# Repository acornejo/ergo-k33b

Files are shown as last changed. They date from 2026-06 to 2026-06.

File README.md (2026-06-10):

# ergo-k33b

A 56-key split/unified ortholinear keyboard with an integrated trackpad, designed in [Ergogen](https://ergogen.xyz/) and routed manually in KiCad.

## Overview

The ergo-k33b is a custom keyboard PCB featuring a symmetric 6×4 column-staggered matrix on each half, palm modifier keys, a 3-key thumb cluster per side, and an optional 65mm×50mm Azoteq TPS65 trackpad mounted in the center of the board.

The board uses a single unified PCB that mirrors the left and right halves — no split cable required.

## Images

### PCB — Top
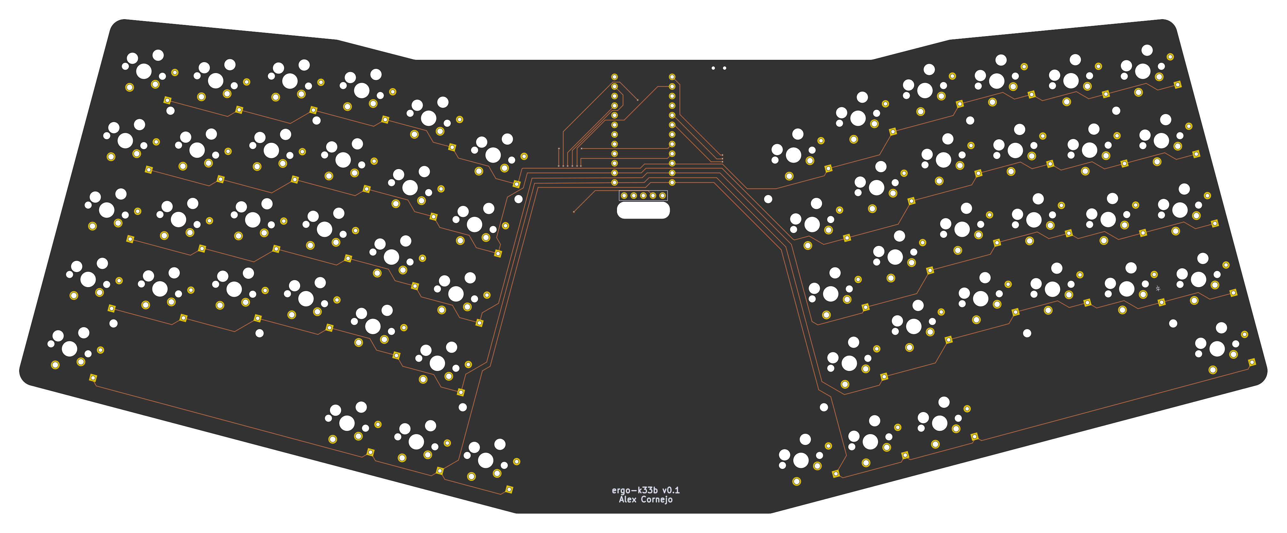
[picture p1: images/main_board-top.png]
PCB Top


### PCB — Bottom
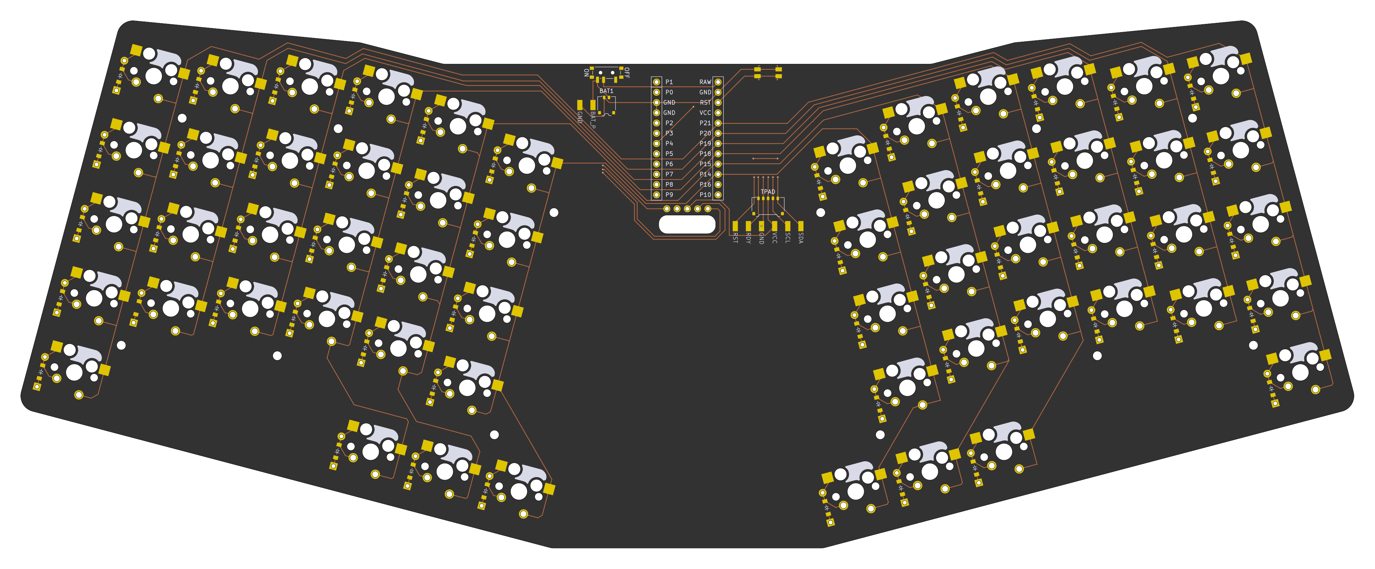
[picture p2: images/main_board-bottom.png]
PCB Bottom


### Front Plate
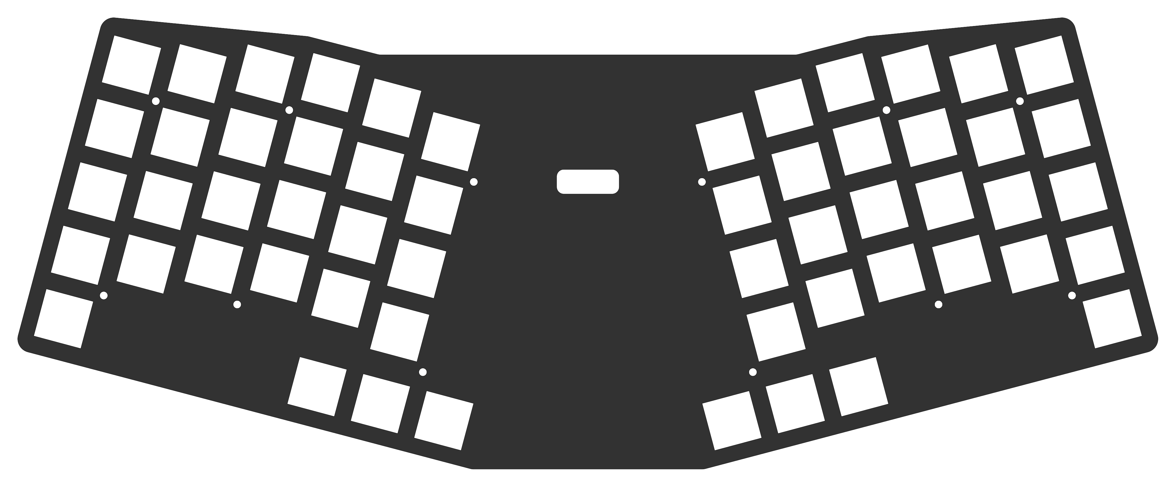
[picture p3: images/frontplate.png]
Front Plate


### Back Plate
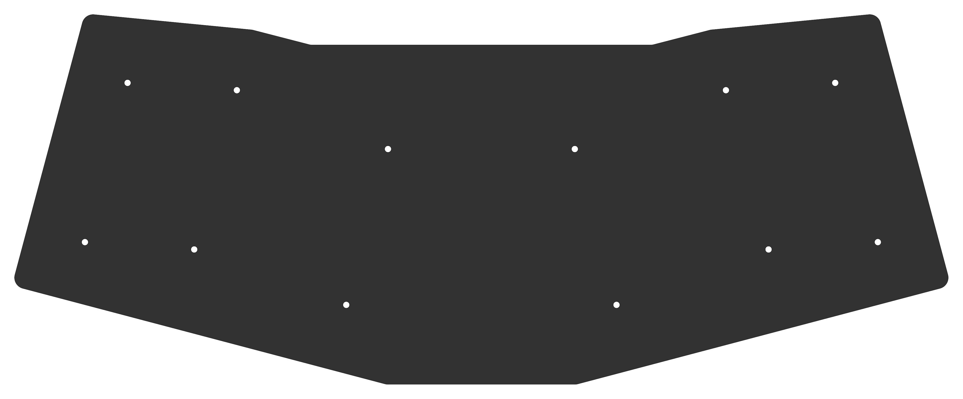
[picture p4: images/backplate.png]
Back Plate


### Case
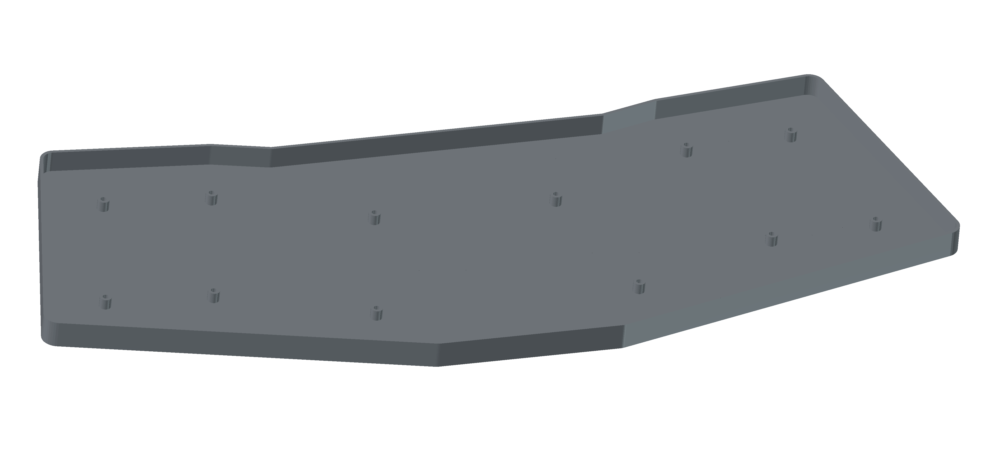
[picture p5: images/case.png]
Case


## Key Layout

- **Total keys:** 56 (10 palm keys + 6 thumb keys + 40 matrix keys)
- **Matrix:** 6 columns × 4 rows per side, with column stagger:
  - Outer/pinky columns: +0/+2.5 mm stagger
  - Ring column: +5 mm stagger
  - Middle column: +2.5 mm stagger
  - Index column: −2.5 mm stagger
  - Inner column: −5 mm stagger
- **Thumb cluster:** 3 keys per side, splayed outward from the inner-bottom matrix position
- **Palm keys:** 1 key per side below the outer column, intended for modifier keys
- **Switch type:** Cherry MX (5-pin), with optional hotswap socket support

## Hardware

| Component | Part | Notes |
|---|---|---|
| MCU | [Nice!Nano](https://nicekeyboards.com/nice-nano/) (nRF52840 SuperMini) | Mounted on the back, centered between halves |
| Display | [Nice!View](https://nicekeyboards.com/nice-view/) | Optional; SPI via P1/P2/P3 |
| Trackpad | [Azoteq TPS65](https://www.azoteq.com/) (65mm × 50mm) | Optional; I²C via P4/P5, ready signal P0 |
| Switches | Cherry MX 5-pin | Hotswap and solder options |
| Diodes | SOD-123 (SMD) + THT | Both footprints populated; one per key |
| Battery connector | Molex Pico EZmate 1×2 | Also exposes BAT\_P / GND solder pads as an alternative |
| Trackpad connector | Molex Pico EZmate 1×5 | Also exposes RST / RDY / GND / VCC / SCL / SDA solder pads as an alternative |
| Power switch | SMD side-mount | On the back of the board |
| Reset button | SMD side-mount | On the back of the board |

### Connector choice

Both the battery and trackpad use [Molex Pico EZmate](https://www.molex.com/en-us/products/connectors/wire-to-board-connectors/pico-ezmate-connectors) connectors rather than the more common JST-PH standard. Pico EZmate has a lower profile (1.48 mm mated height vs. 3.0 mm for JST-PH), which keeps the overall board assembly thinner. Each connector also has corresponding solder pad footprints on the PCB, so you can wire the battery or trackpad directly without a connector if preferred.

## PCB Design

The PCB was designed using [Ergogen](https://ergogen.xyz/) v4.2 to generate the board outline, key positions, and component footprints from `ergogen/config.yaml`. Routing was done manually in KiCad. The freerouting scripts in this repo are provided for experimentation only.

Three PCBs are generated from the Ergogen config:

| PCB | Description |
|---|---|
| `main_board` | The keyboard PCB with all switches, diodes, MCU, and connectors |
| `frontplate` | Switch plate with key cutouts and screw holes |
| `backplate` | Bottom cover plate with screw holes |

A `bottom_case` 3D model (STL) is also generated from the Ergogen outlines using OpenJSCAD.

### Pinout (nRF52840 SuperMini)

| Pin | Function |
|---|---|
| P21 | Column: outer |
| P20 | Column: pinky |
| P19 | Column: ring |
| P18 | Column: middle |
| P15 | Column: index |
| P14 | Column: inner |
| P10 | Row: bottom |
| P8 | Row: home |
| P16 | Row: top |
| P7 | Row: num |
| P9 | Row: thumb cluster |
| P13 | Row: palm keys |
| P0 | Trackpad RDY |
| P4 | Trackpad SCL (I²C) |
| P5 | Trackpad SDA (I²C) |
| P6 | Trackpad RST |
| P1 | Nice!View CS |
| P2 | Nice!View MOSI |
| P3 | Nice!View SCK |

## Repository Structure

```
ergogen/
  config.yaml       # Full Ergogen board definition
output/
  pcbs/             # Generated KiCad PCB files
  cases/            # Generated OpenJSCAD and STL files
  outlines/         # Generated outline DXFs
  gerbers/          # Fabrication outputs
scripts/
  boards.kibot.yaml # KiBot config for main board exports
  default.kibot.yaml# KiBot config for plate exports
  export_dsn.py     # Export KiCad PCB to Specctra DSN
  import_ses.py     # Import Specctra SES back to KiCad
  freerouting.rules # Freerouting design rules
main_board.kicad_pcb # Hand-routed main board (source of truth)
build.sh            # Docker-based build script (KiBot + Freerouting)
images/             # Board renders
```

## Building

### Prerequisites

- [Node.js](https://nodejs.org/) (for Ergogen and OpenJSCAD CLI)
- [Docker](https://www.docker.com/) (for KiBot and Freerouting via containers)

### Generate PCB and case files from Ergogen

```bash
npm install
npm run build
```

This runs Ergogen to regenerate all PCBs, outlines, and case STL files under `output/`.

### Export Gerbers and run autorouting

```bash
./build.sh
```

This uses Docker to:
1. Run [KiBot](https://github.com/INTI-CMNB/KiBot) to export Gerbers for plates and boards
2. Export the board to Specctra DSN format
3. Autoroute with [Freerouting](https://github.com/freerouting/freerouting) (25 passes)
4. Import the routed SES back to KiCad and re-export Gerbers

> **Note:** The hand-routed `main_board.kicad_pcb` at the repo root is the production board. The autorouted output is for experimentation only.

### Clean generated output

```bash
npm run clean
```

## Firmware

The Nice!Nano runs [ZMK Firmware](https://zmk.dev/). Create a ZMK config repo with a shield definition matching the matrix pinout above.

## License

See [LICENSE](LICENSE).

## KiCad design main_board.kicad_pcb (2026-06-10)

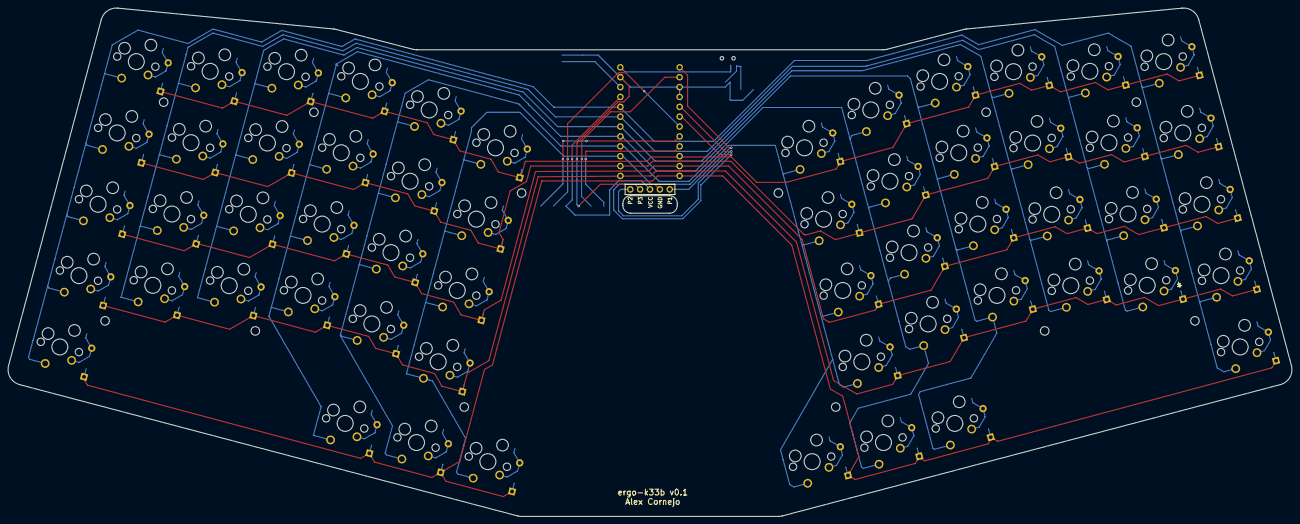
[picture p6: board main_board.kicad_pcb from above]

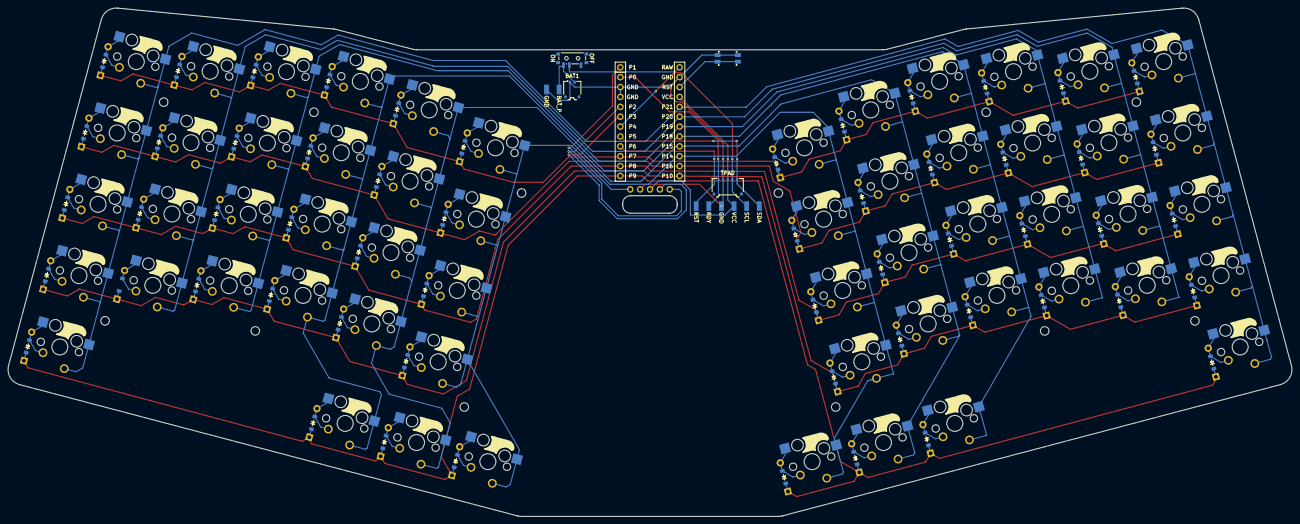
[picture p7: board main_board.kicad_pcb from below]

Board: 2 copper layers, 330.3 x 130.8 mm, 132 parts (116 on the bottom side), 79 nets.

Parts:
BAT1: Molex_Pico-EZmate_78171-0002_1x02-1MP_P1.20mm_Vertical
BAT_PADS1: pads
D1, D2, D3, D4, D5, D6, D7, D8, D9, D10, D11, D12, D13, D14, D15, D16, D17, D18, D19, D20, D21, D22, D23, D24, D25, D26, D27, D28, D29, D30, D31, D32, D33, D34, D35, D36, D37, D38, D39, D40, D41, D42, D43, D44, D45, D46, D47, D48, D49, D50, D51, D52, D53, D54, D55, D56: diode_tht_sod123
DISP1: display_nice_view
MCU1: mcu_supermini_nrf52840
MH1, MH2, MH3, MH4, MH5, MH6, MH7, MH8, MH9, MH10, MH11, MH12: mounting_hole_npth
PWR1: power_switch_smd_side
RST1: reset_switch_smd_side
S1, S2, S3, S4, S5, S6, S7, S8, S9, S10, S11, S12, S13, S14, S15, S16, S17, S18, S19, S20, S21, S22, S23, S24, S25, S26, S27, S28: switch_mx
S29, S30, S31, S32, S33, S34, S35, S36, S37, S38, S39, S40, S41, S42, S43, S44, S45, S46, S47, S48, S49, S50, S51, S52, S53, S54, S55, S56: switch_mx2
TPAD: Molex_Pico-EZmate_78171-0005_1x05-1MP_P1.20mm_Vertical
TPAD_PADS1: pads

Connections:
BAT_P: BAT1.2, BAT_PADS1.1, PWR1.3
GND: BAT1.1, BAT_PADS1.2, DISP1.4, MCU1.3, MCU1.4, MCU1.23, RST1.1, RST1.3, TPAD.2, TPAD_PADS1.4
P0: MCU1.2, TPAD.1, TPAD_PADS1.5
P1: DISP1.5, MCU1.1
P2: DISP1.1, MCU1.5
P3: DISP1.2, MCU1.6
P4: MCU1.7, TPAD.4, TPAD_PADS1.2
P5: MCU1.8, TPAD.5, TPAD_PADS1.1
P6: MCU1.9, TPAD_PADS1.6
P7: D4.1, D8.1, D12.1, D16.1, D20.1, D24.1, D32.1, D36.1, D40.1, D44.1, D48.1, D52.1, MCU1.10
P8: D2.1, D6.1, D10.1, D14.1, D18.1, D22.1, D30.1, D34.1, D38.1, D42.1, D46.1, D50.1, MCU1.11
P9: D25.1, D26.1, D27.1, D28.1, D53.1, D54.1, D55.1, D56.1, MCU1.12
P10: D1.1, D5.1, D9.1, D13.1, D17.1, D21.1, D29.1, D33.1, D37.1, D41.1, D45.1, D49.1, MCU1.13
P14: MCU1.20, S1.1, S2.1, S3.1, S4.1, S28.1, S29.1, S30.1, S31.1, S32.1, S56.1
P15: MCU1.19, S5.1, S6.1, S7.1, S8.1, S33.1, S34.1, S35.1, S36.1
P16: D3.1, D7.1, D11.1, D15.1, D19.1, D23.1, D31.1, D35.1, D39.1, D43.1, D47.1, D51.1, MCU1.14
P18: MCU1.18, S9.1, S10.1, S11.1, S12.1, S37.1, S38.1, S39.1, S40.1
P19: MCU1.17, S13.1, S14.1, S15.1, S16.1, S25.1, S41.1, S42.1, S43.1, S44.1, S53.1
P20: MCU1.16, S17.1, S18.1, S19.1, S20.1, S26.1, S45.1, S46.1, S47.1, S48.1, S54.1
P21: MCU1.15, S21.1, S22.1, S23.1, S24.1, S27.1, S49.1, S50.1, S51.1, S52.1, S55.1
RAW: MCU1.24, PWR1.2
RST: MCU1.22, RST1.2, RST1.4
VCC: DISP1.3, MCU1.21, TPAD.3, TPAD_PADS1.3
far_cluster: D27.2, S27.2
home_cluster: D26.2, S26.2
index_bottom: D17.2, S17.2
index_home: D18.2, S18.2
index_num: D20.2, S20.2
index_top: D19.2, S19.2
inner_bottom: D21.2, S21.2
inner_home: D22.2, S22.2
inner_num: D24.2, S24.2
inner_top: D23.2, S23.2
middle_bottom: D13.2, S13.2
middle_home: D14.2, S14.2
middle_num: D16.2, S16.2
middle_top: D15.2, S15.2
mirror_far_cluster: D55.2, S55.2
mirror_home_cluster: D54.2, S54.2
mirror_index_bottom: D45.2, S45.2
mirror_index_home: D46.2, S46.2
mirror_index_num: D48.2, S48.2
mirror_index_top: D47.2, S47.2
mirror_inner_bottom: D49.2, S49.2
mirror_inner_home: D50.2, S50.2
mirror_inner_num: D52.2, S52.2
mirror_inner_top: D51.2, S51.2
mirror_middle_bottom: D41.2, S41.2
mirror_middle_home: D42.2, S42.2
mirror_middle_num: D44.2, S44.2
mirror_middle_top: D43.2, S43.2
mirror_near_cluster: D53.2, S53.2
mirror_outer_bottom: D29.2, S29.2
mirror_outer_home: D30.2, S30.2
mirror_outer_num: D32.2, S32.2
mirror_outer_top: D31.2, S31.2
mirror_pinky_bottom: D33.2, S33.2
mirror_pinky_home: D34.2, S34.2
mirror_pinky_num: D36.2, S36.2
mirror_pinky_top: D35.2, S35.2
mirror_ring_bottom: D37.2, S37.2
mirror_ring_home: D38.2, S38.2
mirror_ring_num: D40.2, S40.2
mirror_ring_top: D39.2, S39.2
mirror_single_cluster: D56.2, S56.2
near_cluster: D25.2, S25.2
outer_bottom: D1.2, S1.2
outer_home: D2.2, S2.2
outer_num: D4.2, S4.2
outer_top: D3.2, S3.2
pinky_bottom: D5.2, S5.2
pinky_home: D6.2, S6.2
pinky_num: D8.2, S8.2
pinky_top: D7.2, S7.2
ring_bottom: D9.2, S9.2
ring_home: D10.2, S10.2
ring_num: D12.2, S12.2
ring_top: D11.2, S11.2
single_cluster: D28.2, S28.2

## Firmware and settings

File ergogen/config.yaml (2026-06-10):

meta:
  engine: 4.2.0
  name: ergo-k33b
  version: 0.1
  ref: &kb_ref "ErgoK33b v0.1"
  author: hastyrobot
  url: &kb_url https://github.com/acornejo/ergo-k33b

units:
  # Proxy Spacing Variables
  kx: u
  ky: u 
  # Padding Variables
  px: kx + 4
  py: ky + 4
  # key cutout hole size
  kcow: 14
  kcoh: 14

   # Physical measures
  screw_radius: 1.1 # M2 screws
  screw_diameter: screw_radius * 2
  screw_head_radius: 2.05
  screw_head_diameter: screw_head_radius * 2
  spacer_radius: 2.15 # M2 standoffs
  spacer_diameter: spacer_radius * 2

  # case variables
  case_wall_thickness: 1.2
  pcb_to_case_wall_tolerance: 0.25

points:
  zones:
    # 6 x 4 matrix layout
    matrixkeys:
      # Fix placement on KiCAD sheet.
      anchor:
        shift: [100, -100]
      columns:
        # 21, 20, 19, 18, 15, 14
        outer:
          key:
            stagger: 0
            column_net: P21
        pinky:
          key:
            stagger: 2.5
            column_net: P20
        ring:
          key:
            stagger: 5
            column_net: P19
        middle:
          key:
            stagger: 2.5
            column_net: P18
        index:
          key:
            stagger: -2.5
            column_net: P15
        inner:
          key:
            stagger: -5
            column_net: P14
      rows:
        bottom:
          row_net: P10
        home:
          row_net: P8
        top:
          row_net: P16
        num:
          row_net: P7
    thumbkeys:
      anchor:
        ref: matrixkeys_inner_bottom
        shift: [-kx, -ky-2.5]
      columns:
        near:
          key:
            column_net: P18
        home:
       #   key.splay: -5
          key:
            origin: [-11.75, -9]
            column_net: P15
        far:
         # key.splay: -5
          key:
            origin: [-9.5, -9]
            column_net: P14
      rows:
        cluster:
          row_net: P9
    palmkeys:
      anchor:
        ref: matrixkeys_outer_bottom
        shift: [0, -ky]
      columns:
        single:
          key:
            column_net: P21
      rows:
        cluster:
          row_net: P9
    screw_top_outer:
      key:
        width: 2
        height: 2
        rotate: 45
      anchor:
        ref: matrixkeys_outer_num
        shift: [kx/2, -ky/2+1.25]
    screw_bottom_outer:
      key:
        width: 2
        height: 2
        rotate: 45
      anchor:
        ref: matrixkeys_outer_bottom
        shift: [kx/2, -ky/2]
    screw_top_middle:
      key:
        width: 2
        height: 2
        rotate: 45
      anchor:
        ref: matrixkeys_middle_num
        shift: [-kx/2, -ky/2-1.25]
    screw_bottom_middle:
      key:
        width: 2
        height: 2
        rotate: 45
      anchor:
        ref: matrixkeys_middle_bottom
        shift: [-kx/2, -ky/2-2.5]
    screw_top_inner:
      key:
        width: 2
        height: 2
        rotate: 45
      anchor:
        ref: matrixkeys_inner_num
        shift: [kx/2, -ky/2]
    screw_bottom_inner:
      key:
        width: 2
        height: 2
        rotate: 45
      anchor:
        ref: matrixkeys_inner_bottom
        shift: [kx/2, -ky/2]
    mcu:
      key:
        width: 18
        height: 38
        mirror.skip: true
        rotate: 15
      anchor:
        shift: [36.75,16.5]
        ref: matrixkeys_inner_num
    trackpad:
      key:
        width: 65
        height: 50
        mirror:
          skip: true
        rotate: 15
      anchor:
        shift: [49.5, -32]
        ref: matrixkeys_inner_num


  rotate: -15
  mirror:
    ref: matrixkeys_inner_bottom
    distance: kx + 90
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
